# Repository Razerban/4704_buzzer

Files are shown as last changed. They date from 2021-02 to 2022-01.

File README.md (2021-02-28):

# 4704_buzzer
A recreation of the IBM 4704 Series buzzer board

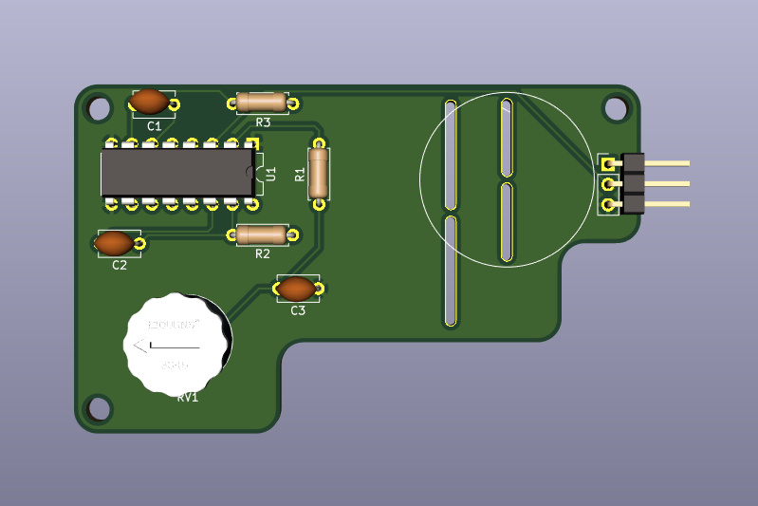
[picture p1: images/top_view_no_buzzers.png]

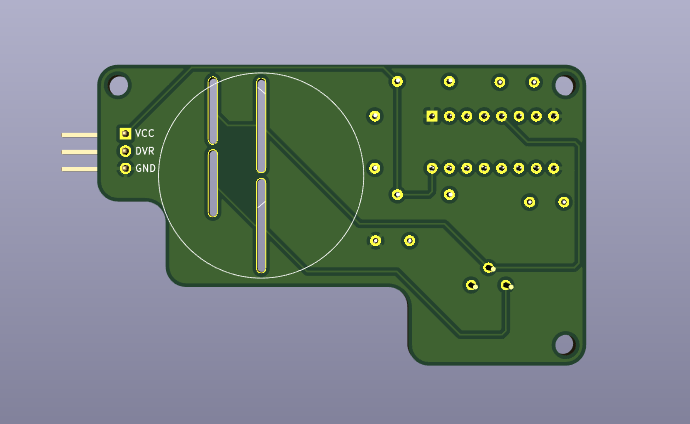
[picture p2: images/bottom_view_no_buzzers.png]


This board has been reverse engineered from a buzzer board found in a genuine IBM 4704 Series Model F 107 keyboard.

# PCB design notes
Due to the physical constraints of the space available inside the IBM 4704 Series Model F keyboard cases for housing the buzzer board, only 7.5mm of height is available to house a physical buzzer mounted on the top of the PCB.
However, due to the availability and different shapes and dimensions (and the cost) of the buzzers available in the market, it's not easy (and cheap) to find one that would satisfy these constraints.
So I decided to add a second footprint on the bottom of the PCB that would allow to take advantage of the space available underneath the board to house a bigger buzzer.

The maximum dimensions of the buzzers that would be compatible with this board are:
- BZ1 (Buzzer installed on the bottom of the PCB): L=30mm, W=30mm, H=16.5mm

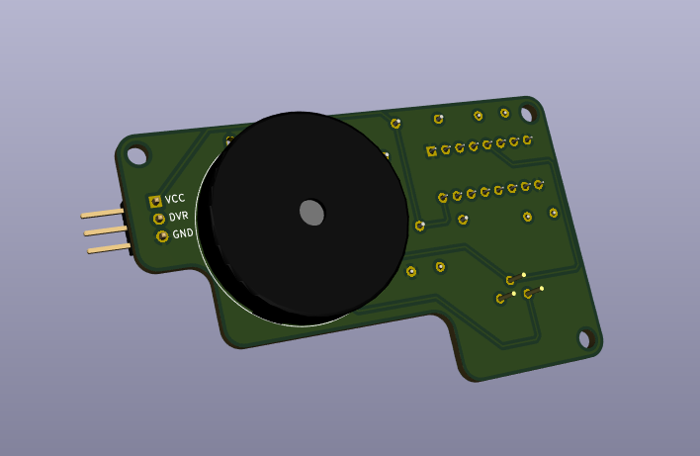
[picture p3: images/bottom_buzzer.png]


- BZ2 (Buzzer installed on the top of the PCB): L=22mm, W=22mm, H=7mm

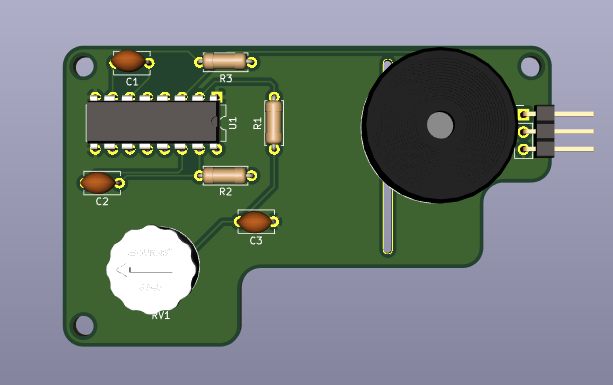
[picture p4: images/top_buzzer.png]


These dimensions work for 1.6mm thick PCB boards.
While I don't recommend this, you could choose a less thick PCB when ordering the board from your PCB Fabrication Manufacturer.
This would let you choose a bigger (height wise) buzzer to mount on the top or bottom of the PCB, however, beware that the PCB might not be able to sit correctly inside the case.

# Ordering from JLCPCB
1) Go to http://jlcpcb.com , sign in to your account (create one if you don't have one)
2) Click Order Now
3) Upload the .zip file from the "production" subfolder
4) Select PCB Qty you wish to build
5) Set "Remove Order Number" to "Specify a location"

# BOM
- C1: 20nF
- C2: 20nF
- C3: 7nF
- R1: 330
- R2: 27K
- R3: 27K
- RV1: 20K (I recommend Bourns 3345P-1-203-T)

# License
You can redistribute this project and/or modify it under the terms of the
GNU General Public License as published by the Free Software Foundation,
either version 3 of the License, or (at your option) any later version.

This program is distributed in the hope that it will be useful,
but WITHOUT ANY WARRANTY; without even the implied warranty of
MERCHANTABILITY or FITNESS FOR A PARTICULAR PURPOSE.  See the
GNU General Public License for more details.

You should have received a copy of the GNU General Public License
along with this program.  If not, see <http://www.gnu.org/licenses/>.

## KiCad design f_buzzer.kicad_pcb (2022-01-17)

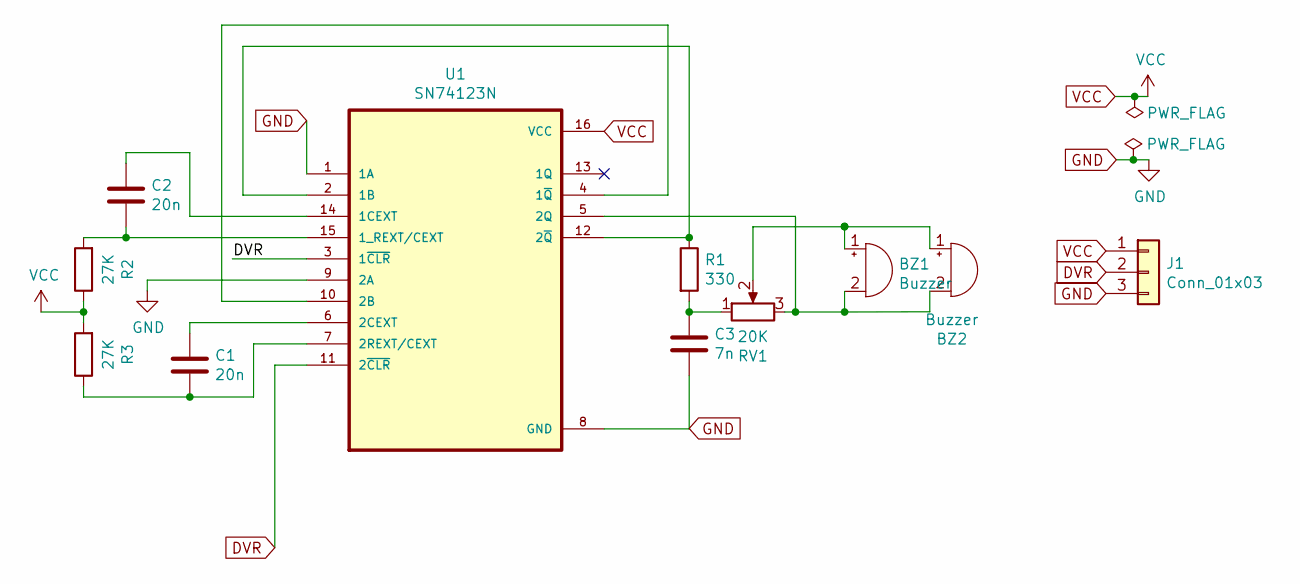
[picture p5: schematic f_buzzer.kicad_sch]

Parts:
BZ1: Buzzer; buzzer_bottom
BZ2: Buzzer; buzzer_front
C1, C2: 20n; C_Disc_D5.1mm_W3.2mm_P5.00mm
C3: 7n; C_Disc_D5.1mm_W3.2mm_P5.00mm
J1: Conn_01x03; PinHeader_1x03_P2.54mm_Horizontal
R1: 330; R_Axial_DIN0207_L6.3mm_D2.5mm_P7.62mm_Horizontal
R2, R3: 27K; R_Axial_DIN0207_L6.3mm_D2.5mm_P7.62mm_Horizontal
RV1: 20K; Potentiometer_Bourns_3345P_Horizontal
U1: SN74123N; DIP-16_W7.62mm_Socket

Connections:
DVR: J1.2, U1.3 (1~CLR), U1.11 (2~CLR)
GND: C3.2, J1.3, U1.1 (1A), U1.8 (GND), U1.9 (2A)
unnamed: BZ1.1 (-), BZ2.1 (-), RV1.2
unnamed: BZ1.2 (+), BZ2.2 (+), RV1.3, U1.5 (2Q)
unnamed: C1.1, U1.6 (2CEXT)
unnamed: C1.2, R3.1, U1.7 (2REXT/CEXT)
unnamed: C2.1, U1.14 (1CEXT)
unnamed: C2.2, R2.2, U1.15 (1_REXT/CEXT)
unnamed: C3.1, R1.2, RV1.1
unnamed: R1.1, U1.2 (1B), U1.12 (2~Q)
unnamed: U1.4 (1~Q), U1.10 (2B)
VCC: J1.1, R2.1, R3.2, U1.16 (VCC)

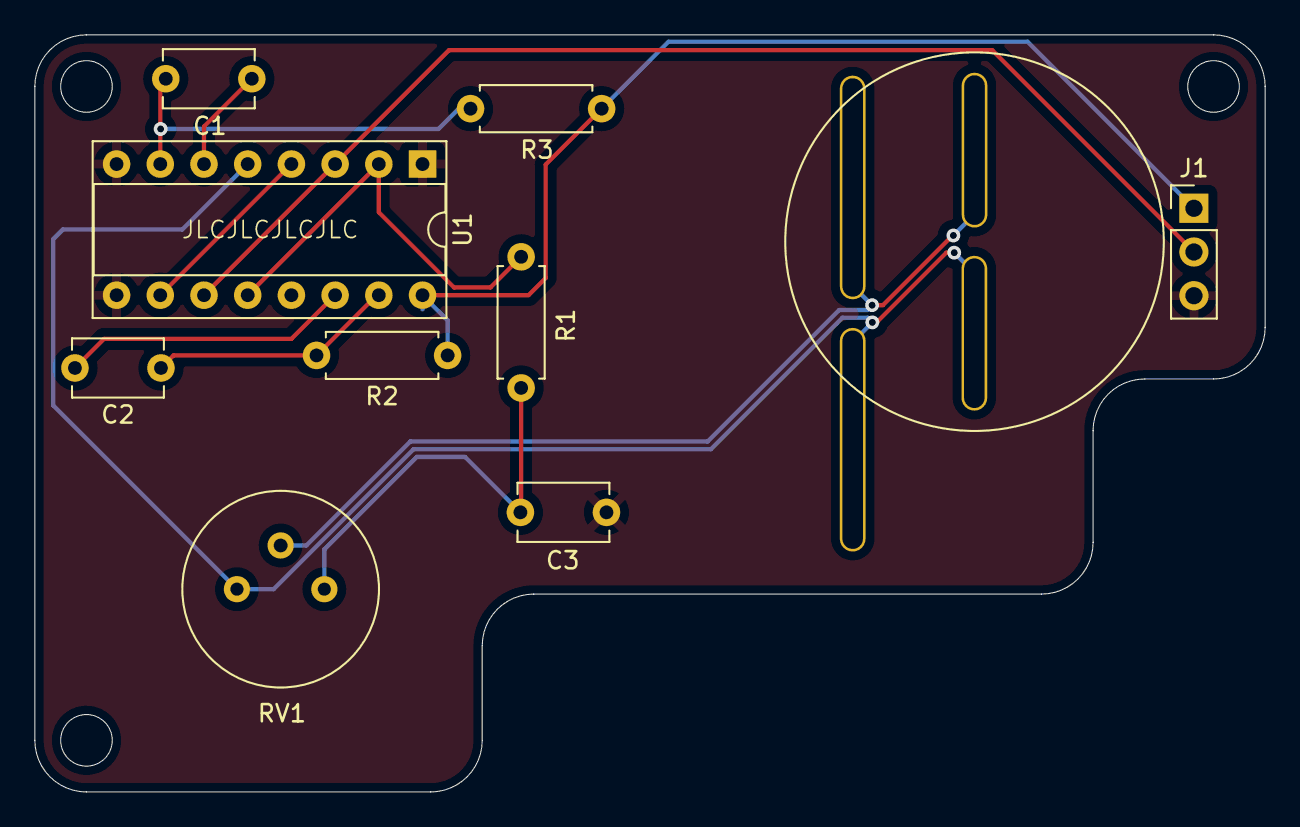
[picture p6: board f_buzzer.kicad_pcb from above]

Board: 2 copper layers, 71.5 x 44.0 mm, 11 parts (1 on the bottom side), 12 nets.

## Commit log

2021-02-05 Initial sketch
    [f_buzzer.kicad_pcb, f_buzzer.sch]
2021-02-06 Added the 3D model for the potentiometer
    [Bourne 3345P - T.stp]
2021-02-06 Fixed connections in schematic
    [f_buzzer.kicad_pcb, f_buzzer.sch]
2021-02-06 Added some constraints related to the case
    [f_buzzer.kicad_pcb, f_buzzer.sch]
2021-02-06 Created a generic footprint for 22mm (diameter) Buzzer
2021-02-06 Created a generic footprint for 28mm (diameter) Buzzer
2021-02-06 Replaced the buzzer with the 22mm generic one
    [f_buzzer.kicad_pcb, f_buzzer.sch]
2021-02-06 Changed the footprint to be able to house 30mm (diameter) buzzers
2021-02-06 Added 3D models for the footprints
2021-02-06 Placed the two buzzers for 3D rendering of the board
    [f_buzzer.kicad_pcb, f_buzzer.sch]
2021-02-06 Added fill zones
    [f_buzzer.kicad_pcb]
2021-02-06 Relocated some components
    [f_buzzer.kicad_pcb]
2021-02-06 Added JLCPCB magic string
    [f_buzzer-B_Cu.gbr, f_buzzer-B_Mask.gbr, f_buzzer-B_Paste.gbr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]
2021-02-09 Colored the 3D models
    [f_buzzer.kicad_pcb]
2021-02-09 Added C3 value to the schematic
    [f_buzzer.sch]
2021-02-09 Updated latest gerbers file
    [f_buzzer-B_Cu.gbr, f_buzzer-B_Mask.gbr, f_buzzer-B_Paste.gbr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]
2021-02-13 Changed the buzzer footprints
    [f_buzzer.kicad_pcb]
2021-02-28 Changed the potentiometer footprint
    [f_buzzer-B_Cu.gbr, f_buzzer-B_Mask.gbr, f_buzzer-B_Paste.gbr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]
2022-01-16 Update to KiCad 6
    [f_buzzer-B_Cu.gbr, f_buzzer-B_Mask.gbr, f_buzzer-B_Paste.gbr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]
2022-01-17 Rearranged the components
    [f_buzzer.kicad_pcb, f_buzzer.kicad_sch]
2022-01-17 Added latest gerber version
    [f_buzzer.kicad_pcb]
